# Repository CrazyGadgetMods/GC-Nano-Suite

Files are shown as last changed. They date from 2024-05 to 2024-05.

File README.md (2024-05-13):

# GC Nano


This repo contains the suite of custom PCBs required to build the GC Nano v1 / v1.1, with the exception of the [PSU-Plus](https://github.com/CrazyGadgetMods/PSU-Plus). All 3D model files (as well as a more formal release post) can be found in the [GC Nano - The Worlds Smallest Gamecube](https://bitbuilt.net/forums/index.php?threads/gc-nano-the-worlds-smallest-gamecube.5697/) thread on the BitBuilt Forums.

## Top Board
- USB type C port with 5.1k ohm resistors on each of the CC lines to enable any Power Delivery (PD) compliant charger to output 5V @ 3A.
- MAX16054 Push-On / Push-Off IC paired with a PFET to turn the system on and off with a single tact switch
- GL823K Micro SD to USB converter IC.
- USB MUX - when the system is off, the USB data lines connect to the USB-C port, allowing file transfer without having to open up the case; when the system is on, the USB data lines go to two pads which get soldered to the Wii.
- Sync and Reset buttons to be soldered to the bluetooth module / Wii.

## Controller Board
- Solders right to the TRRS jacks, eliminating the need for any daisy-chain hand-wiring between the ports.
- Three power pads are wired to the complimentary set on the top board for clean assembly.
- Data lines get wired to the Wii
- Incorporates pull-up resistors for the data lines, as the original resistor array is cut off for the OMEGA trim.

## HDMI-FFC
- Allows us to mount the HDMI port to the back handle, as well as interface it with the AVE-HDMI via an FFC cable.

## Credits
- [Wesk](https://bitbuilt.net/forums/index.php?members/wesk.1486/): Inviting me to collaborate on the GC Nano project, creating the GC Micro
- [Madmorda](https://bitbuilt.net/forums/index.php?members/madmorda.554/): Creating the original [World's Smallest Gamecube](https://www.youtube.com/watch?v=_BxwS_uTKt4)
- [YveltalGriffin](https://github.com/mackieks): Advice while designing the Top Board / PSU-Plus
- [BitBuilt](https://bitbuilt.net/): Being the best modding community out there!

## License
Solderpad Hardware License v2.1

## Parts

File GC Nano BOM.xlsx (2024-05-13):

 | Link | Link
Top Board
Controller Board
HDMI FFC
PSU-Plus |  | https://www.etsy.com/listing/1510321427
GCC Extension Cables | https://www.amazon.com/dp/B09W9557WT
3.5mm TRRS Plugs | https://www.aliexpress.us/item/3256805371689272.html
19 pin FFC, 100mm, 0.5mm pitch | https://www.ebay.com/itm/185956450093?var=693966125813
Nand Flex | https://4layertech.com/products/rvl-nand-flex-board-pack-of-2 | https://github.com/mackieks/nandFlex
AVE-HDMI / FujiFlex | https://electron-shepherd.com/products/ave-hdmi-kit?sca_ref=3751270.b4SFOiSBw4 | https://github.com/mackieks/fujiflex
Fan | https://www.amazon.com/dp/B07RMGVBKL
Heatsink | https://www.amazon.com/dp/B07CVT7P25
Copper Plate (55x30mm) | https://www.onlinemetals.com/en/buy/copper/0-032-copper-sheet-110-o/pid/24684
Thermal Tape | https://www.amazon.com/dp/B094VMDTH3
Thermal Epoxy | https://www.arcticsilver.com/arctic_silver_thermal_adhesive.htm
M2.5x4, M2.5x5 Screws
Short Silver Wii Screws | Harvest from the Wii

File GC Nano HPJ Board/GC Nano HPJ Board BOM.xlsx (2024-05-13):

Ref Des | Qty | Manufacturer PN | Digikey PN | Description
R1, R2, R3, R4 | 4 | RC0603FR-07698RL | 311-698HRCT-ND | RES 698 OHM 1% 1/10W 0603
J1, J2, J3, J4 | 4 | ASJ-165-M-G-HDW-1 | 2057-ASJ-165-M-G-HDW-1-ND | AUDIO JACK

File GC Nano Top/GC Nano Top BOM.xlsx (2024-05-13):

Ref Des | Qty | Manufacturer PN | Digikey PN | Description
U1 | 1 | GL823K | N/A | USB 2.0 SD/MSPRO Card Reader Controller
U2 | 1 | MAX16054AZT+T | MAX16054AZT+TCT-ND | IC INTFACE SPECIALIZED TSOT23-6
U3 | 1 | PI3USB221AZUAEX | PI3USB221AZUAEXDICT-ND | IC USB2 SWITCH 3V UQFN2015-10
C1, C2, C5, C7 | 4 | CL10A105KA8NNNC | 1276-1102-1-ND | CAP CER 1UF 25V X5R 0603
C3, C4, C6, C8 | 4 | CL10B104KB8NNWC | 1276-1935-1-ND | CAP CER 0.1UF 50V X7R 0603
D1 | 1 | LTST-C191KGKT | 160-1446-1-ND | LED GREEN CLEAR SMD
D2 | 1 | LTST-C191KFKT | 160-1445-1-ND | LED ORANGE CLEAR SMD
J1 | 1 | 2171790001 | 900-2171790001CT-ND | CONN RCP USB2.0 TYP C 24P SMD RA
J2 | 1 | MEM2075-00-140-01-A | 2073-MEM2075-00-140-01-ACT-ND | MICRO SD PUSH-PUSH, SMT, 1.40MM
Q1 | 1 | PMPB17EPX | 1727-PMPB17EPXCT-ND | P-CHANNEL TRENCH MOSFET
R1, R2 | 2 | RC0603FR-135K1L | 13-RC0603FR-135K1LCT-ND | RES 5.1K OHM 1% 1/10W 0603
R3, R5 | 2 | WR06X331 JTL | 1292-WR06X331JTLCT-ND | RES 330 OHM 5% 1/10W 0603
R4, R6 | 2 | CR0603-JW-104ELF | CR0603-JW-104ELFCT-ND | RES SMD 100K OHM 5% 1/10W 0603
SW1, SW2, SW3 | 3 | TS02-66-43-BK-260-LCR-D | 2223-TS02-66-43-BK-260-LCR-D-ND | 6 X 6 MM, 4.3 MM ACTUATOR HEIGHT

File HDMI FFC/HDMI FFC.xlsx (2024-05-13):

Ref Des | Qty | Manufacturer PN | Digikey PN | Description
 | 1 | 10029449-111RLF | 609-4614-1-ND | CONN RCPT 1.4 HDMI 19POS SMD R/A
 | 1 | 1-1734839-9 | A101338CT-ND | CONN FPC TOP 19POS 0.5MM R/A

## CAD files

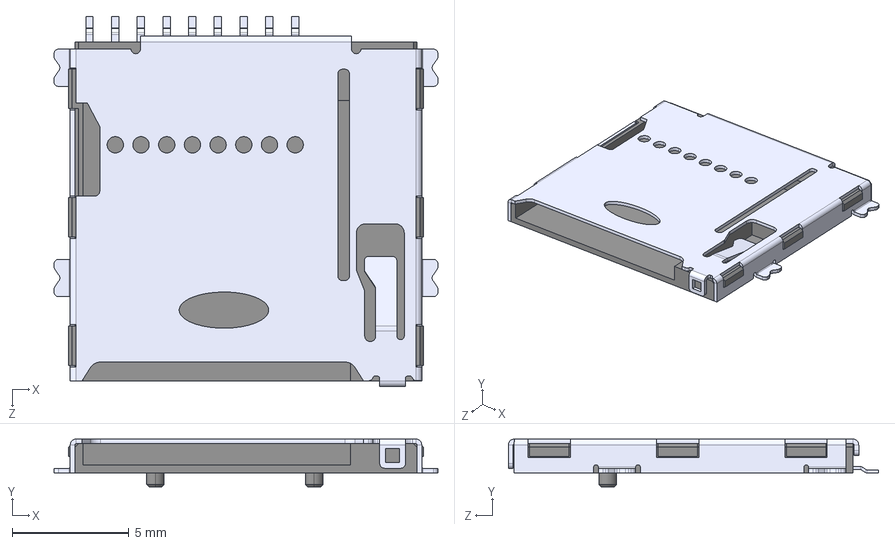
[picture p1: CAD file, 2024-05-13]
GC Nano Top/Symbols-Footprints-3D_Models/MEM2075-00-140-01-A--3DModel-STEP-56544.STEP
16.4 x 2.05 x 15.9 mm

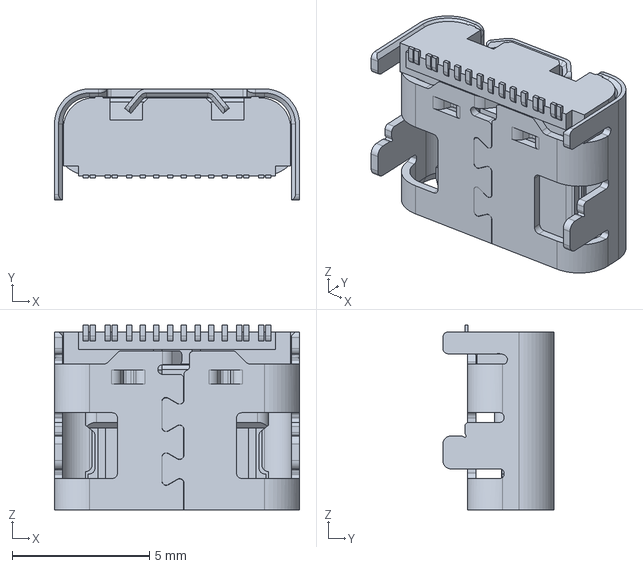
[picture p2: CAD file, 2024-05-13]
GC Nano Top/Symbols-Footprints-3D_Models/ul_2171790001/2171790001.stp
8.94 x 4.06 x 6.75 mm

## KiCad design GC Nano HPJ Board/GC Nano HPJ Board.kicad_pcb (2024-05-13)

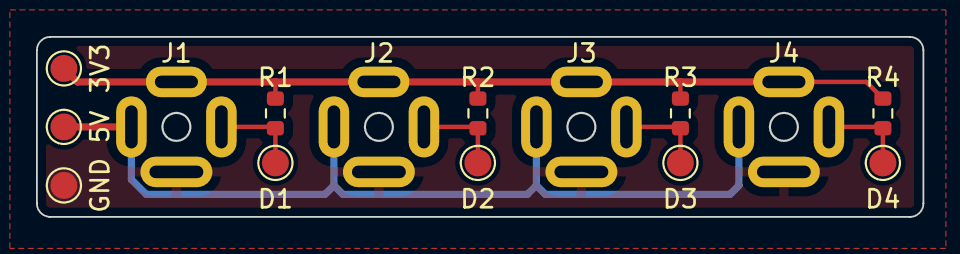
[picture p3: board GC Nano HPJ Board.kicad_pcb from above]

Board: 2 copper layers, 49.2 x 10.0 mm, 15 parts (0 on the bottom side), 7 nets.

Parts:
3V3: 3V3; TestPoint_Pad_D1.5mm
5V: 5V; TestPoint_Pad_D1.5mm
D1, D2, D3, D4: GCD; TestPoint_Pad_D1.5mm
GND: GND; TestPoint_Pad_D1.5mm
J1, J2, J3, J4: ASJ-165-M-G-HDW-1
R1, R2, R3, R4: 10k; R_0603_1608Metric

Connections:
+3V3: 3V3.1, J1.3 (Ring_1), J2.3 (Ring_1), J3.3 (Ring_1), J4.3 (Ring_1), R1.2, R2.2, R3.2, R4.2
+5V: 5V.1, J1.2 (Tip), J2.2 (Tip), J3.2 (Tip), J4.2 (Tip)
GND: GND.1, J1.1 (Sleeve), J2.1 (Sleeve), J3.1 (Sleeve), J4.1 (Sleeve)
unnamed: D1.1, J1.4 (Ring_2), R1.1
unnamed: D2.1, J2.4 (Ring_2), R2.1
unnamed: D3.1, J3.4 (Ring_2), R3.1
unnamed: D4.1, J4.4 (Ring_2), R4.1

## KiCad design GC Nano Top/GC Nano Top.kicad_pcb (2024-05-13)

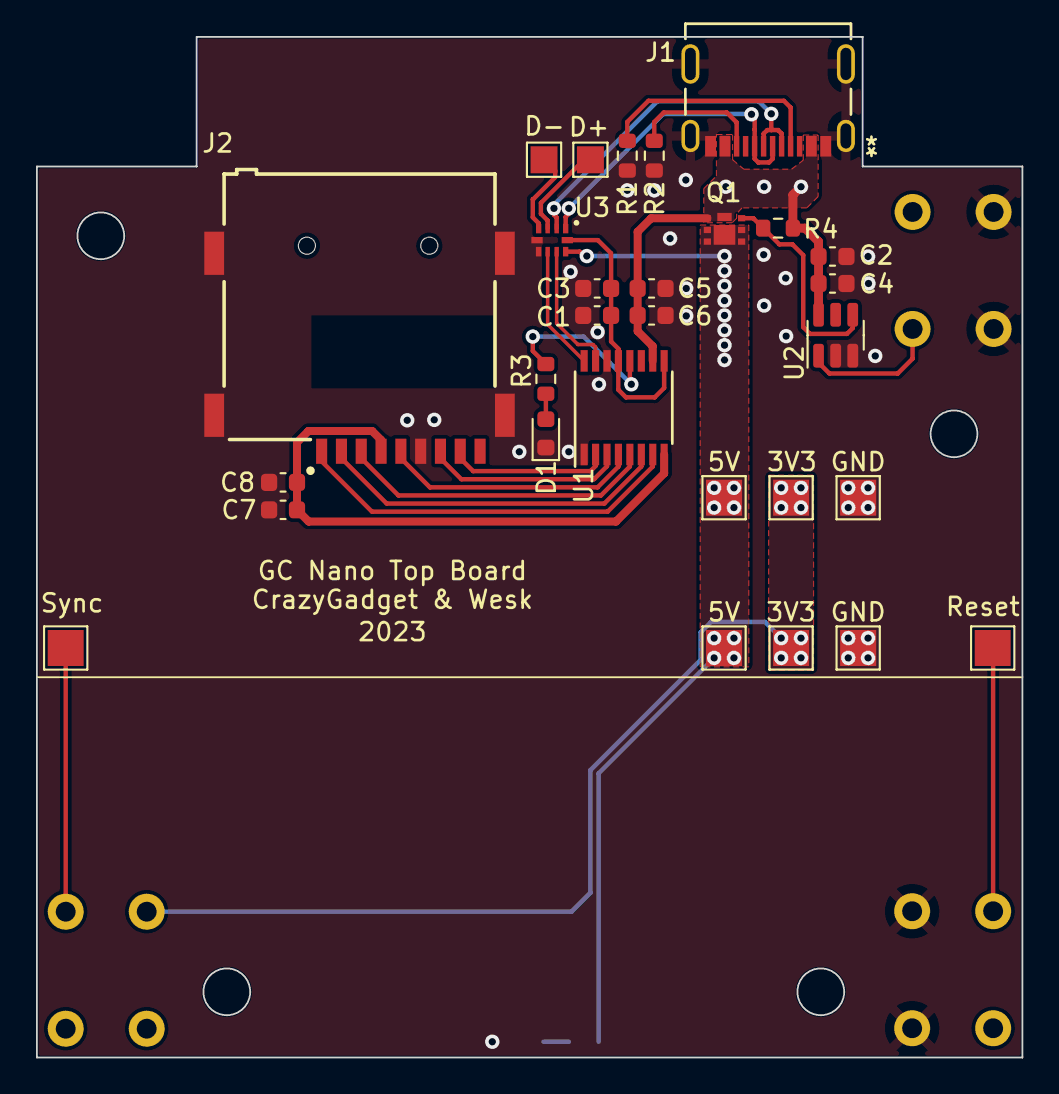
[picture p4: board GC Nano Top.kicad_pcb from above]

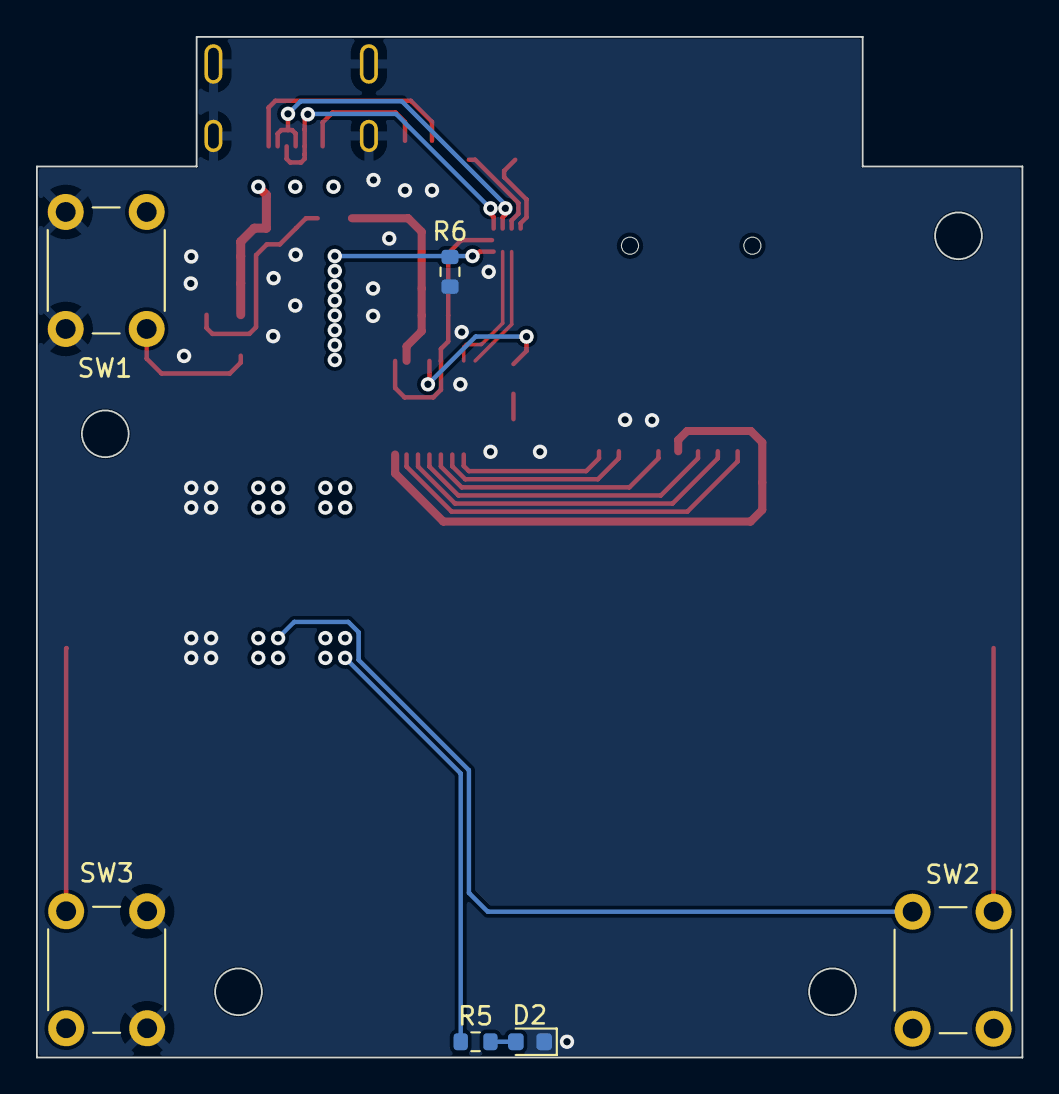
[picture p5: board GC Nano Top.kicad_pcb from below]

Board: 2 copper layers, 54.8 x 56.7 mm, 35 parts (6 on the bottom side), 27 nets.

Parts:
3V3, 3V3#2: 3V3; TestPoint_Pad_2.0x2.0mm
5V: 5V; TestPoint_Pad_2.0x2.0mm
5V#2: 5V_SW; TestPoint_Pad_2.0x2.0mm
C1, C2, C5, C7: 1u; C_0603_1608Metric
C3, C4, C6, C8: 0.1u; C_0603_1608Metric
D1, D2: LED; LED_0603_1608Metric
D+: D+Wii; TestPoint_Pad_1.5x1.5mm
D-: D-Wii; TestPoint_Pad_1.5x1.5mm
GND: GND; TestPoint_Pad_2.0x2.0mm
GND#2: GND; TestPoint_Pad_2.0x2.0mm
J1: USB_C_Receptacle_USB2.0; 2171790001_MOL
J2: MEM2075-00-140-01-A; GCT_MEM2075-00-140-01-A
Q1: PMPB17EP
R1, R2: 5.1k; R_0603_1608Metric
R3, R5: 330; R_0603_1608Metric
R4: 100k; R_0603_1608Metric
R6: R_0603_1608Metric
Reset: Reset; TestPoint_Pad_2.0x2.0mm
SW1, SW2, SW3: SW_Push; SW_PUSH_6mm
Sync: Sync; TestPoint_Pad_2.0x2.0mm
U1: GL823K-HCY04; SSOP-16_3.9x4.9mm_P0.635mm
U2: MAX16054; TSOT-23-6
U3: PI3USB221AZUAEX; PI3USB221A

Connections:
3V3: 3V3.1, 3V3#2.1, SW2.1
3V3_MUX: C1.1, C3.1, U1.9 (VDD), U1.13 (VDDA), U3.10 (VDD)
5V_IN: C2.1, C4.1, C5.1, C6.1, J1.A4/B9, J1.B4/A9, Q1.4 (S), Q1.8 (S), R4.2, U1.10 (5V), U2.6 (VCC)
5V_SW: 5V.1, 5V#2.1, Q1.1 (D), Q1.2 (D), Q1.5 (D), Q1.6 (D), Q1.7 (D), R5.1, R6.2, U3.9 (S)
CLK: J2.P5 (CLK), U1.4 (CLK)
CMD: J2.P3 (CMD), U1.5 (CMD)
D0: J2.P7 (DAT0), U1.3 (D0)
D1: J2.P8 (DAT1), U1.2 (D1)
D2: J2.P1 (DAT2), U1.7 (D2)
D3: J2.P2 (CD/DAT3), U1.6 (D3)
D+: U1.15 (DP), U3.8 (D+)
D+C: J1.A6 (D+), J1.B6 (D+), U3.1 (1D+)
D-: U1.16 (DM), U3.7 (D-)
D-C: J1.A7 (D-), J1.B7 (D-), U3.2 (1D-)
GND: C1.2, C2.2, C3.2, C4.2, C5.2, C6.2, C7.2, C8.2, D1.1 (K), D2.1 (K), GND.1, GND#2.1, J1.13, J1.14, J1.15, J1.16, J1.A1/B12, J1.B1/A12, J2.P6 (VSS), J2.SH1 (SHIELD), J2.SH2 (SHIELD), J2.SH3 (SHIELD), J2.SH4 (SHIELD), R1.2, R2.2, R6.1, SW1.1, SW3.1, U1.1 (VSS), U1.14 (VSS), U2.2 (GND), U2.3 (CLEAR), U3.5 (GND), U3.6 (~{OE)
unnamed: D1.2 (A), R3.2
unnamed: D2.2 (A), R5.2
unnamed: J1.A5 (CC1), R1.1
unnamed: J1.B5 (CC2), R2.1
unnamed: R3.1, U1.12 (LED)
unnamed: SW1.2, U2.1 (IN)
unnamed: SW2.2, Sync.1
unnamed: Reset.1, SW3.2
unnamed: D+.1, U3.3 (2D+)
unnamed: D-.1, U3.4 (2D-)
SD_PMOS: C7.1, C8.1, J2.P4 (VDD), U1.8 (PMOS)
~OUT: Q1.3 (G), R4.1, U2.4 (~OUT)

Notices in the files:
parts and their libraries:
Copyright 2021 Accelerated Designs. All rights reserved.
